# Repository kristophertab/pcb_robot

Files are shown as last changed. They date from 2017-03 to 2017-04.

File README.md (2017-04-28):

# PCB do robota
Płytka z mcu, optoizolowanym połączeniem uart, połączeniem st-link, kilkoma poziomami zasilania. Ma za zadanie sterować odczytywać dane z enkoderów i sterować, przez mostki, pracą silników
### Schemat
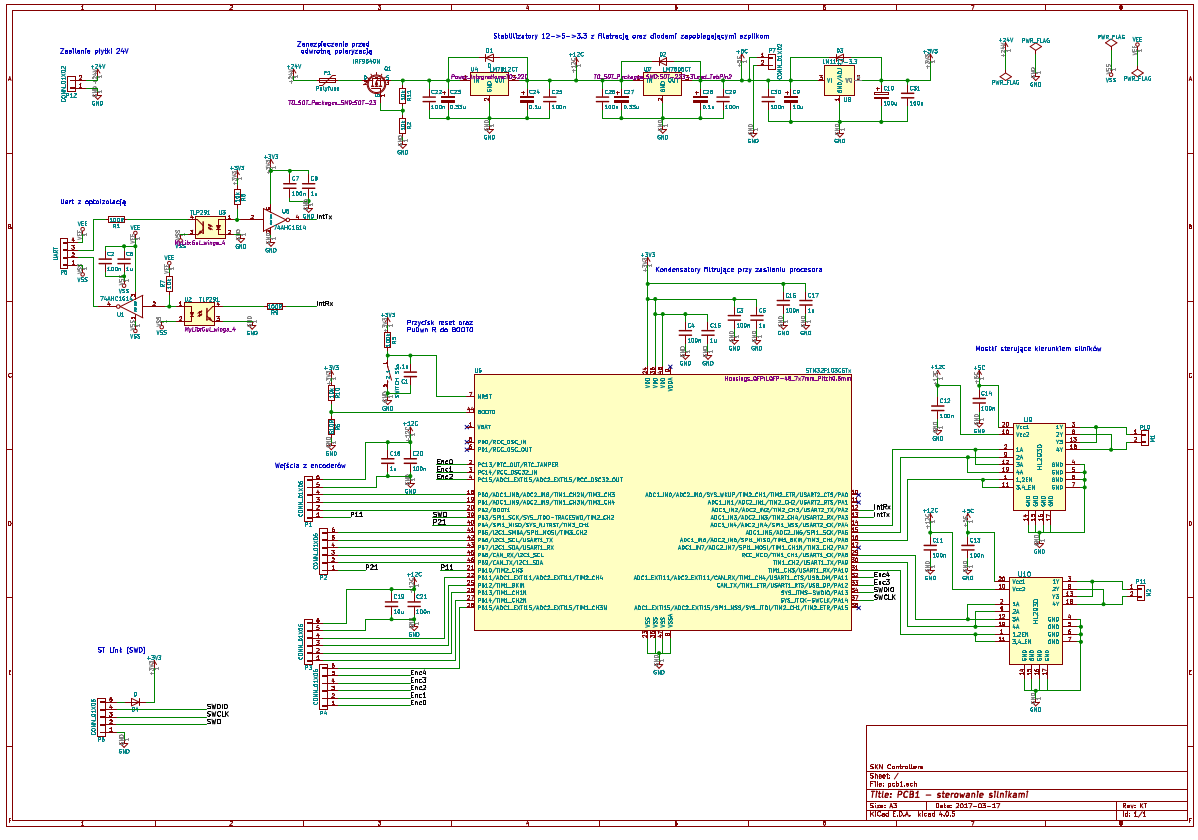
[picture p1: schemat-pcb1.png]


### PCB
Górna warstwa:

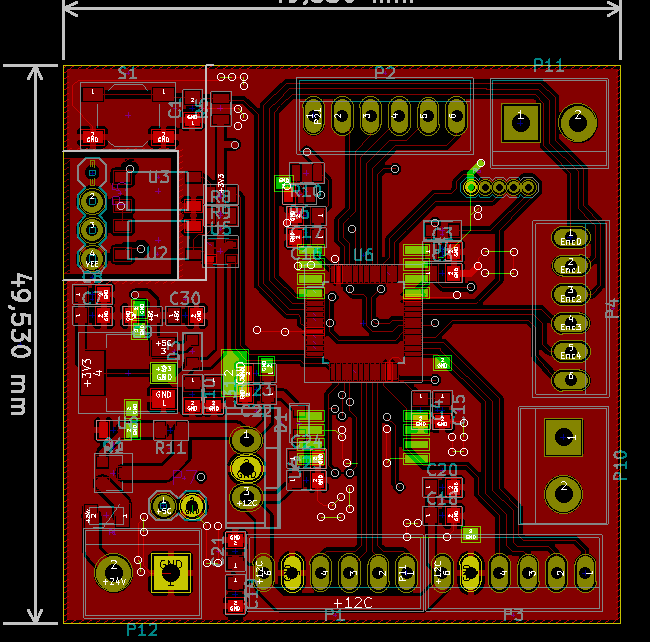
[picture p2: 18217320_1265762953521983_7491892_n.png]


Dolna warstwa:

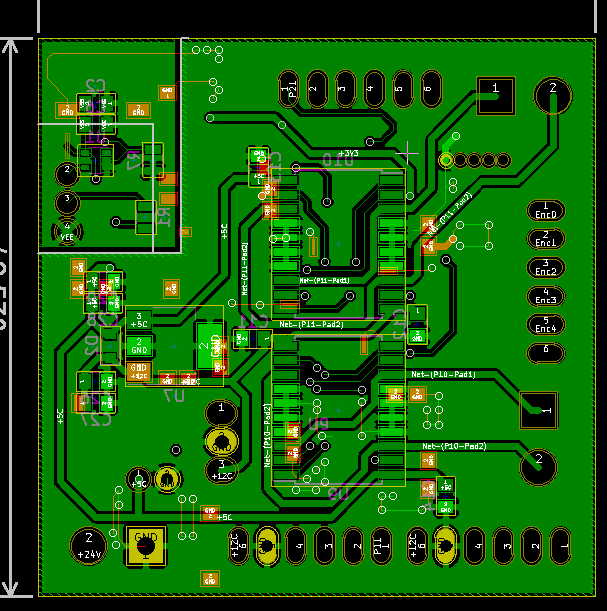
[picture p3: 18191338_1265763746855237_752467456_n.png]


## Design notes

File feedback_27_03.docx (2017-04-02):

1. Boot zworka

rys z manuala:

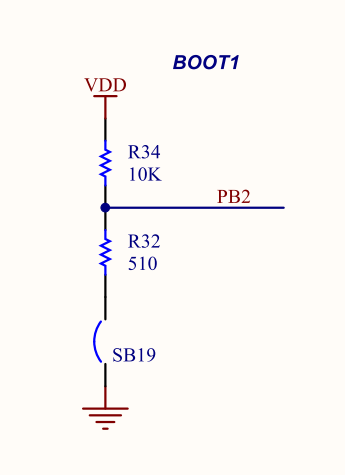
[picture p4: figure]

A tak na schemacie jest:

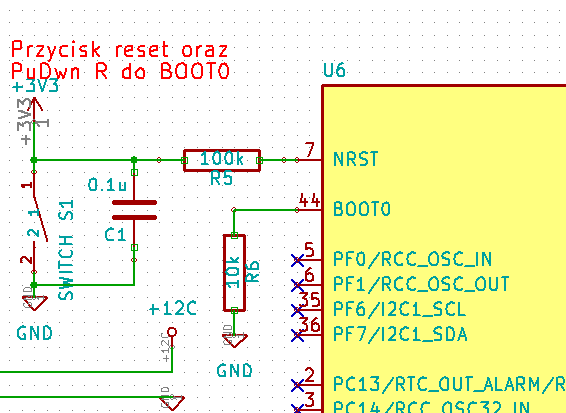
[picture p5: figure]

2. Dzielnik dla mosfeta wejściowego

tak na schemacie jest:

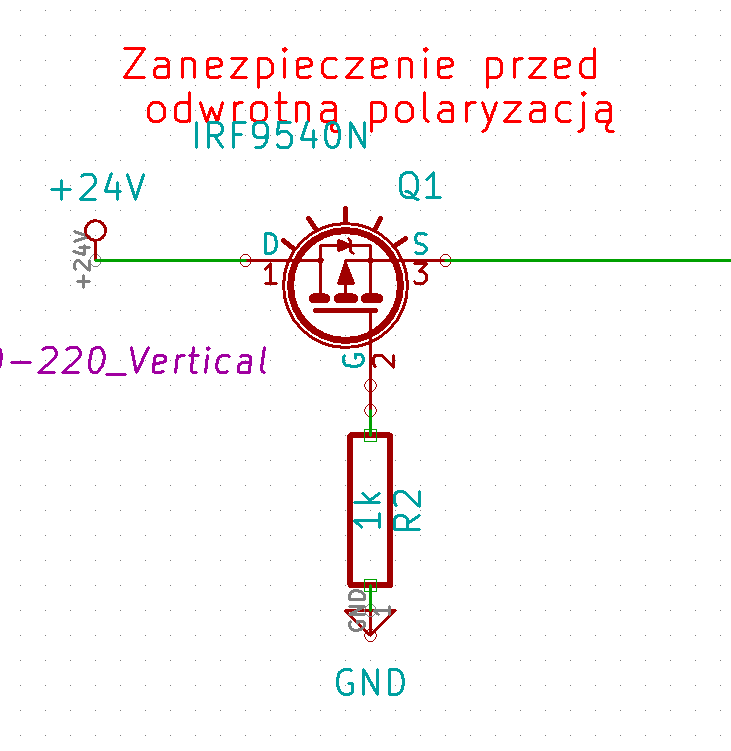
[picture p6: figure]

Powinno być tak:

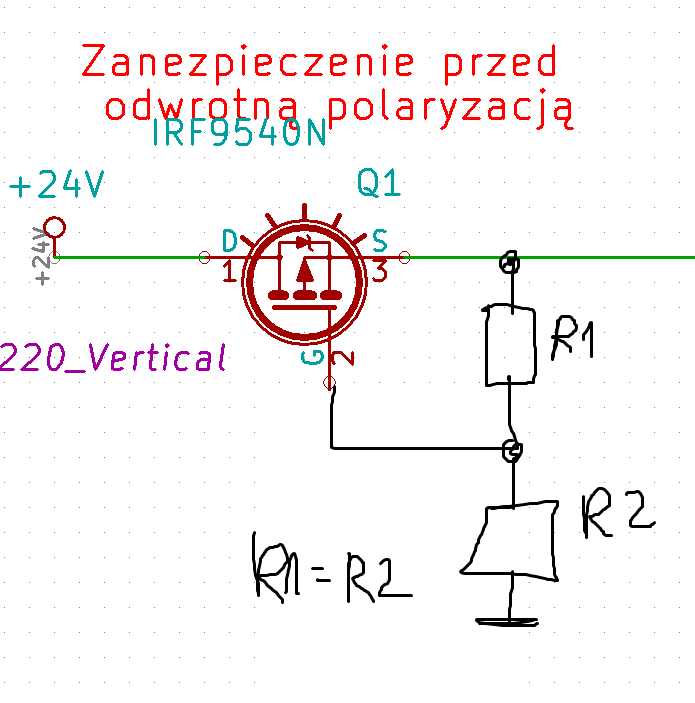
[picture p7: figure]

Ponieważ(nota katalogowa IRF5305 mosfet typu P):

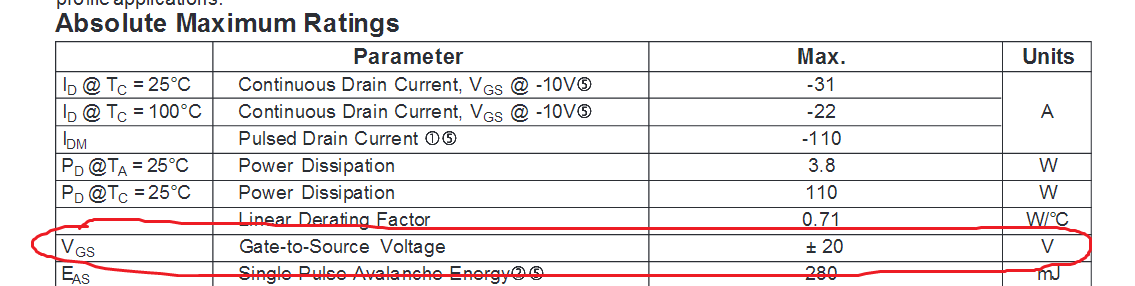
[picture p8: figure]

http://www.irf.com/product-info/datasheets/data/irf5305s.pdf

3. Rezystory poprawić(pull-up 10k i szeregowo rezystory 100R) i kondesatory dodac( 100nF i 1uF )

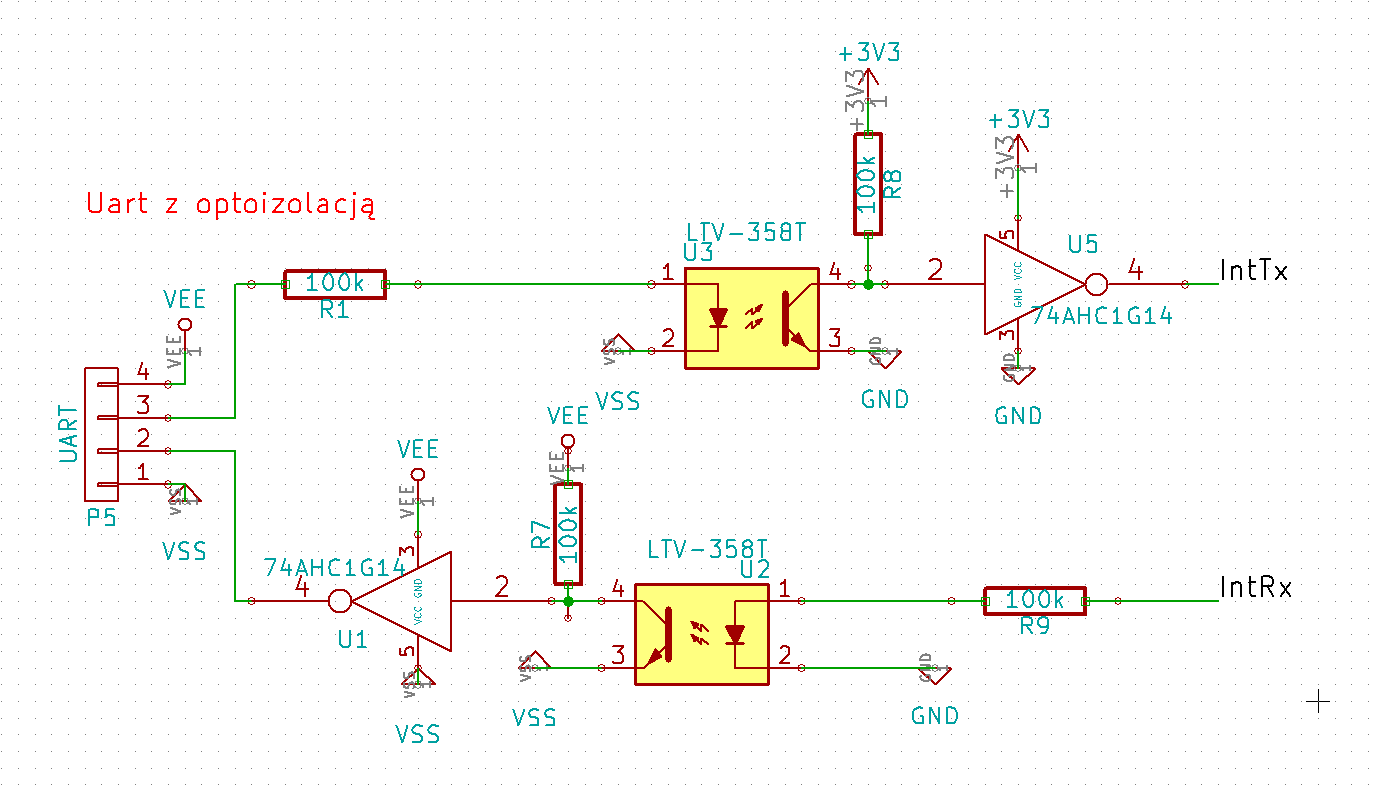
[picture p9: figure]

4. Bezpiecznik polimerowy na samym wejściu w napięciu 24V dac na 2A jakos
5. Ujednolisci symbol kondensatorow elektrolitycznych i dodac ceramiczne, po jednym na kazda strone stabilizatorów, wartości jakies 100nF

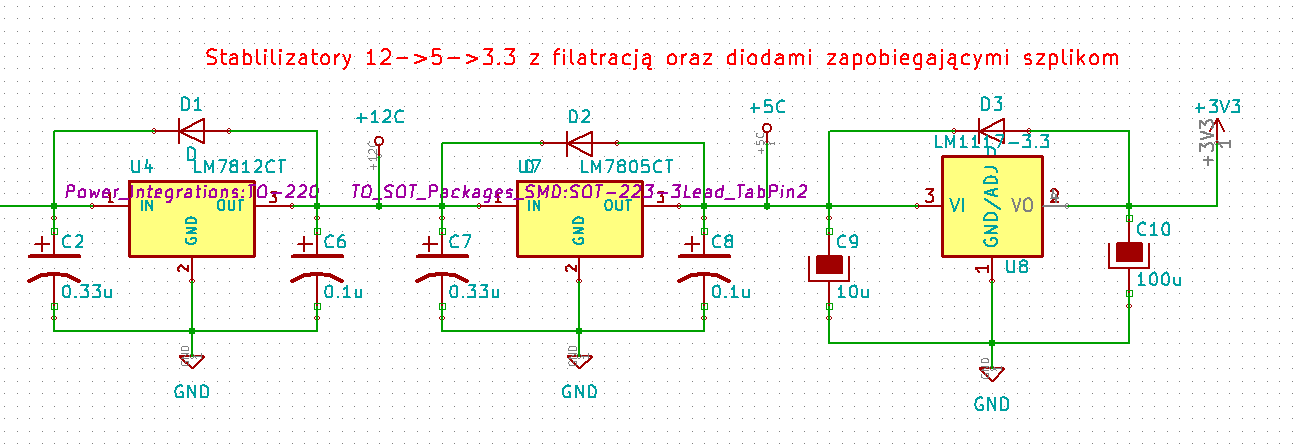
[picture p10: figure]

6. SWD zworke poprawić i odpowiednio podlaczyc

Manual:

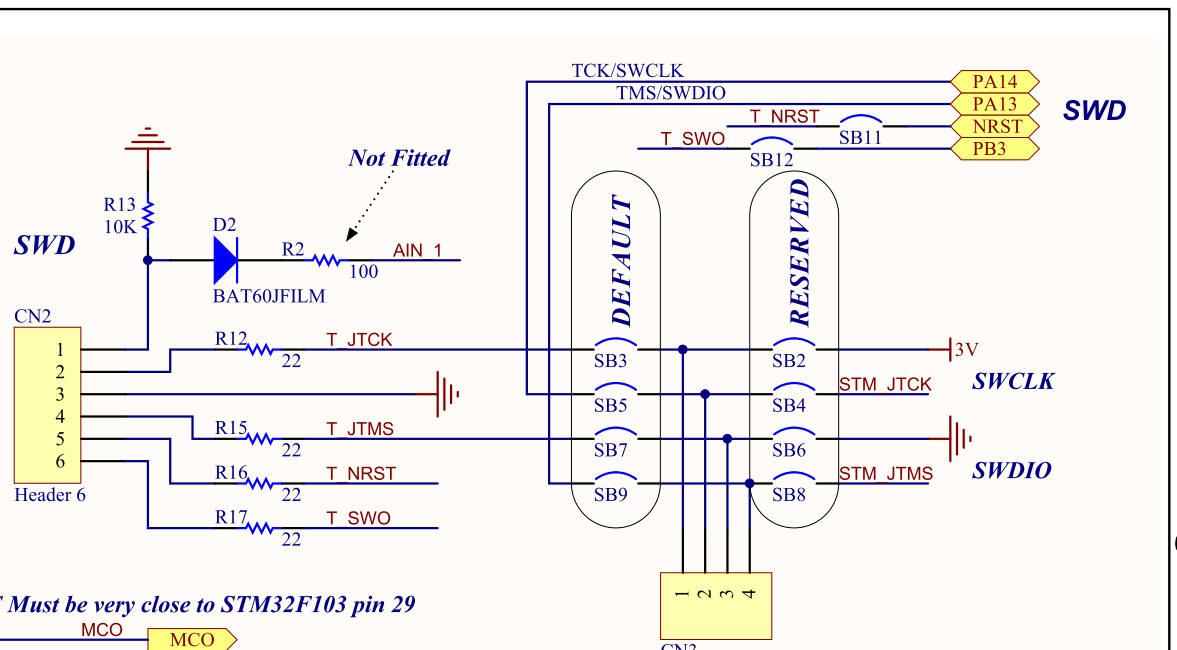
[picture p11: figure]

Tak jest na schemacie:

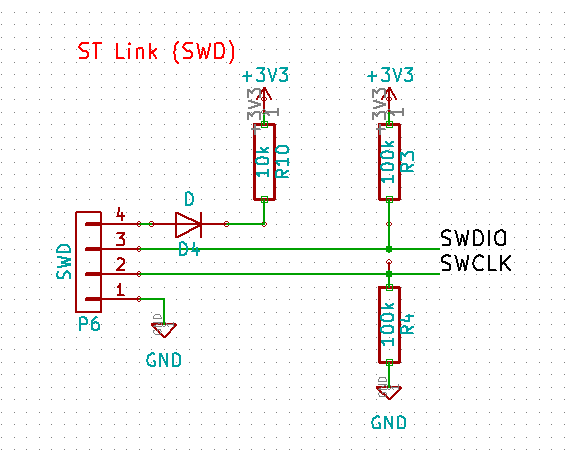
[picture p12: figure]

Dodatkowo: usunąć rezystor 100k miedzy dioda a 3.3V – inaczej nie zasilimy naszego układu

7. Zewrzec do masy Vss

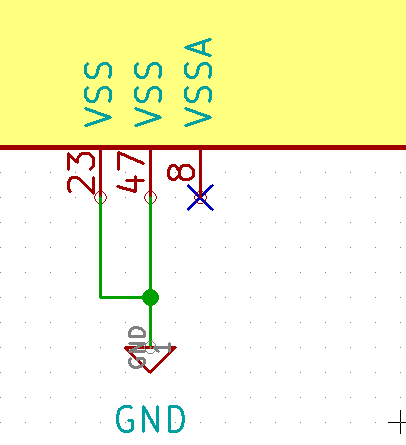
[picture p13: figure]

8. Dodac kondensatory 100nF i 1uF na wejścia zaislaniua do enkoderów

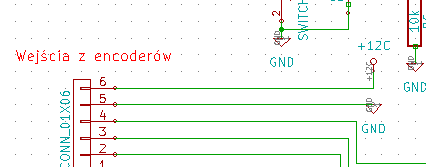
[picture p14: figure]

9. Reset podlaczenie poprawić

Manual:

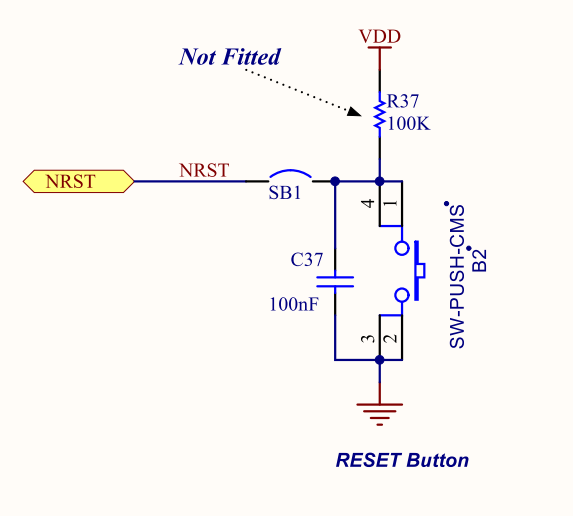
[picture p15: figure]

Schemat:

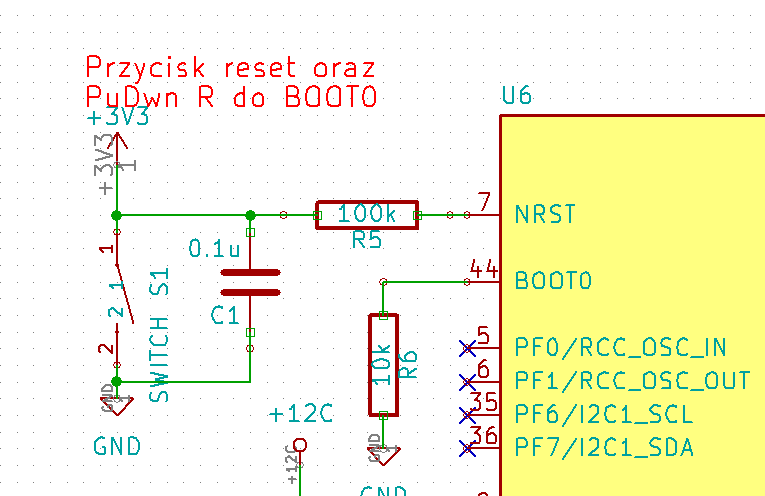
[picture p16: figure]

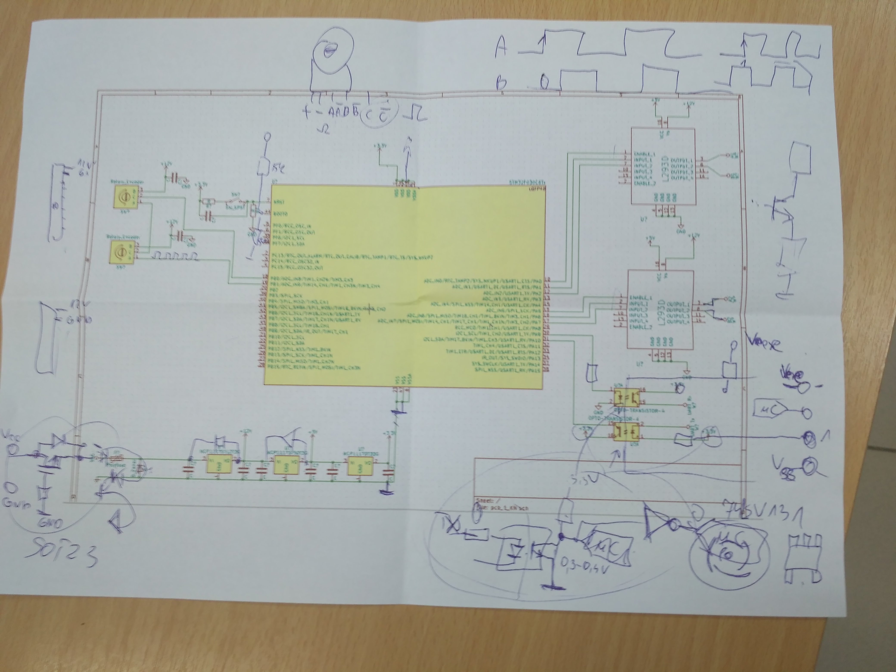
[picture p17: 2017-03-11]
poprawki_pcb1.jpg

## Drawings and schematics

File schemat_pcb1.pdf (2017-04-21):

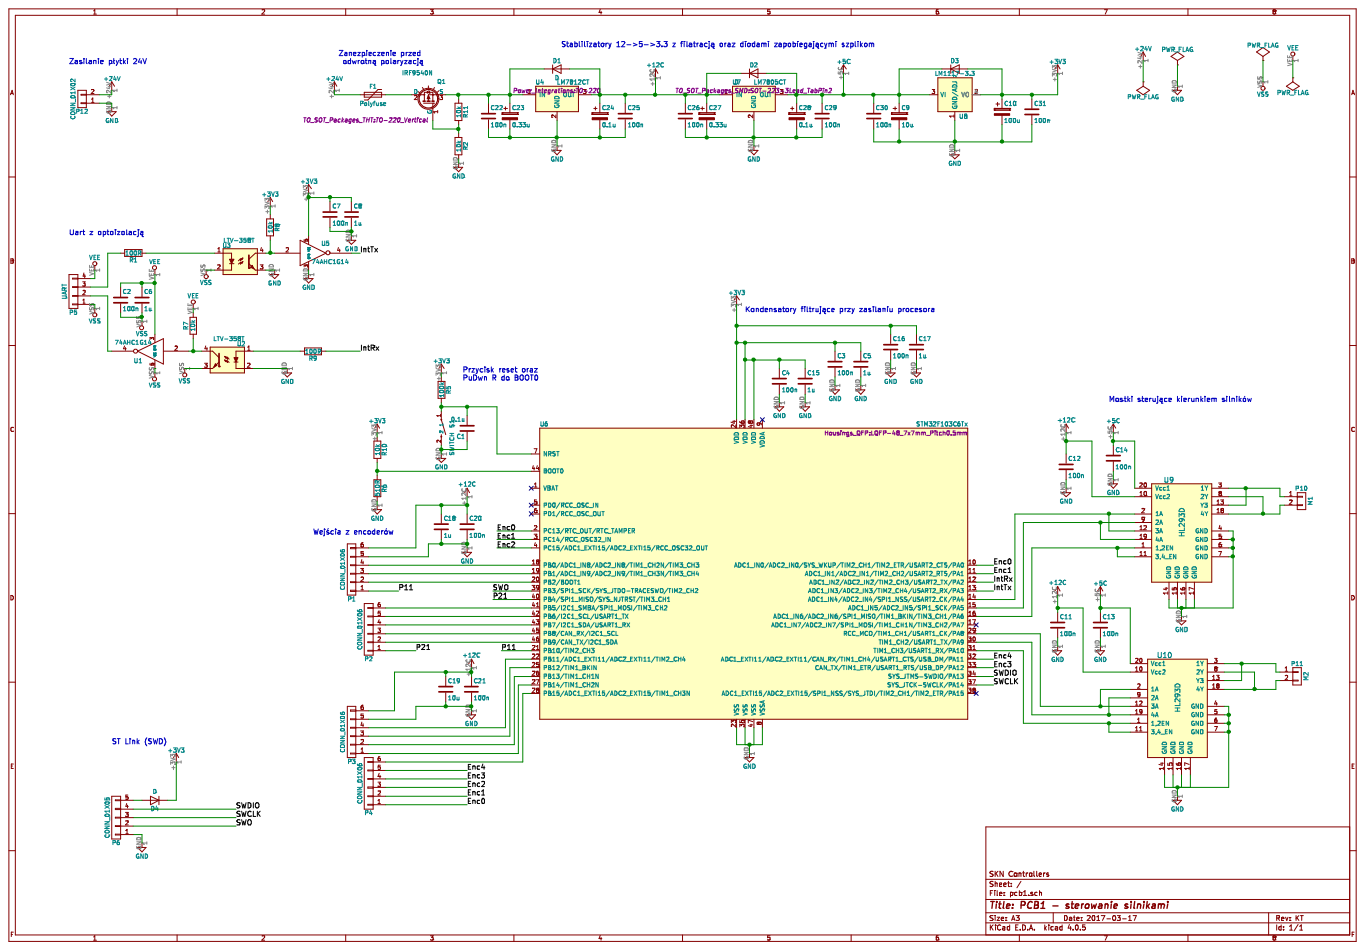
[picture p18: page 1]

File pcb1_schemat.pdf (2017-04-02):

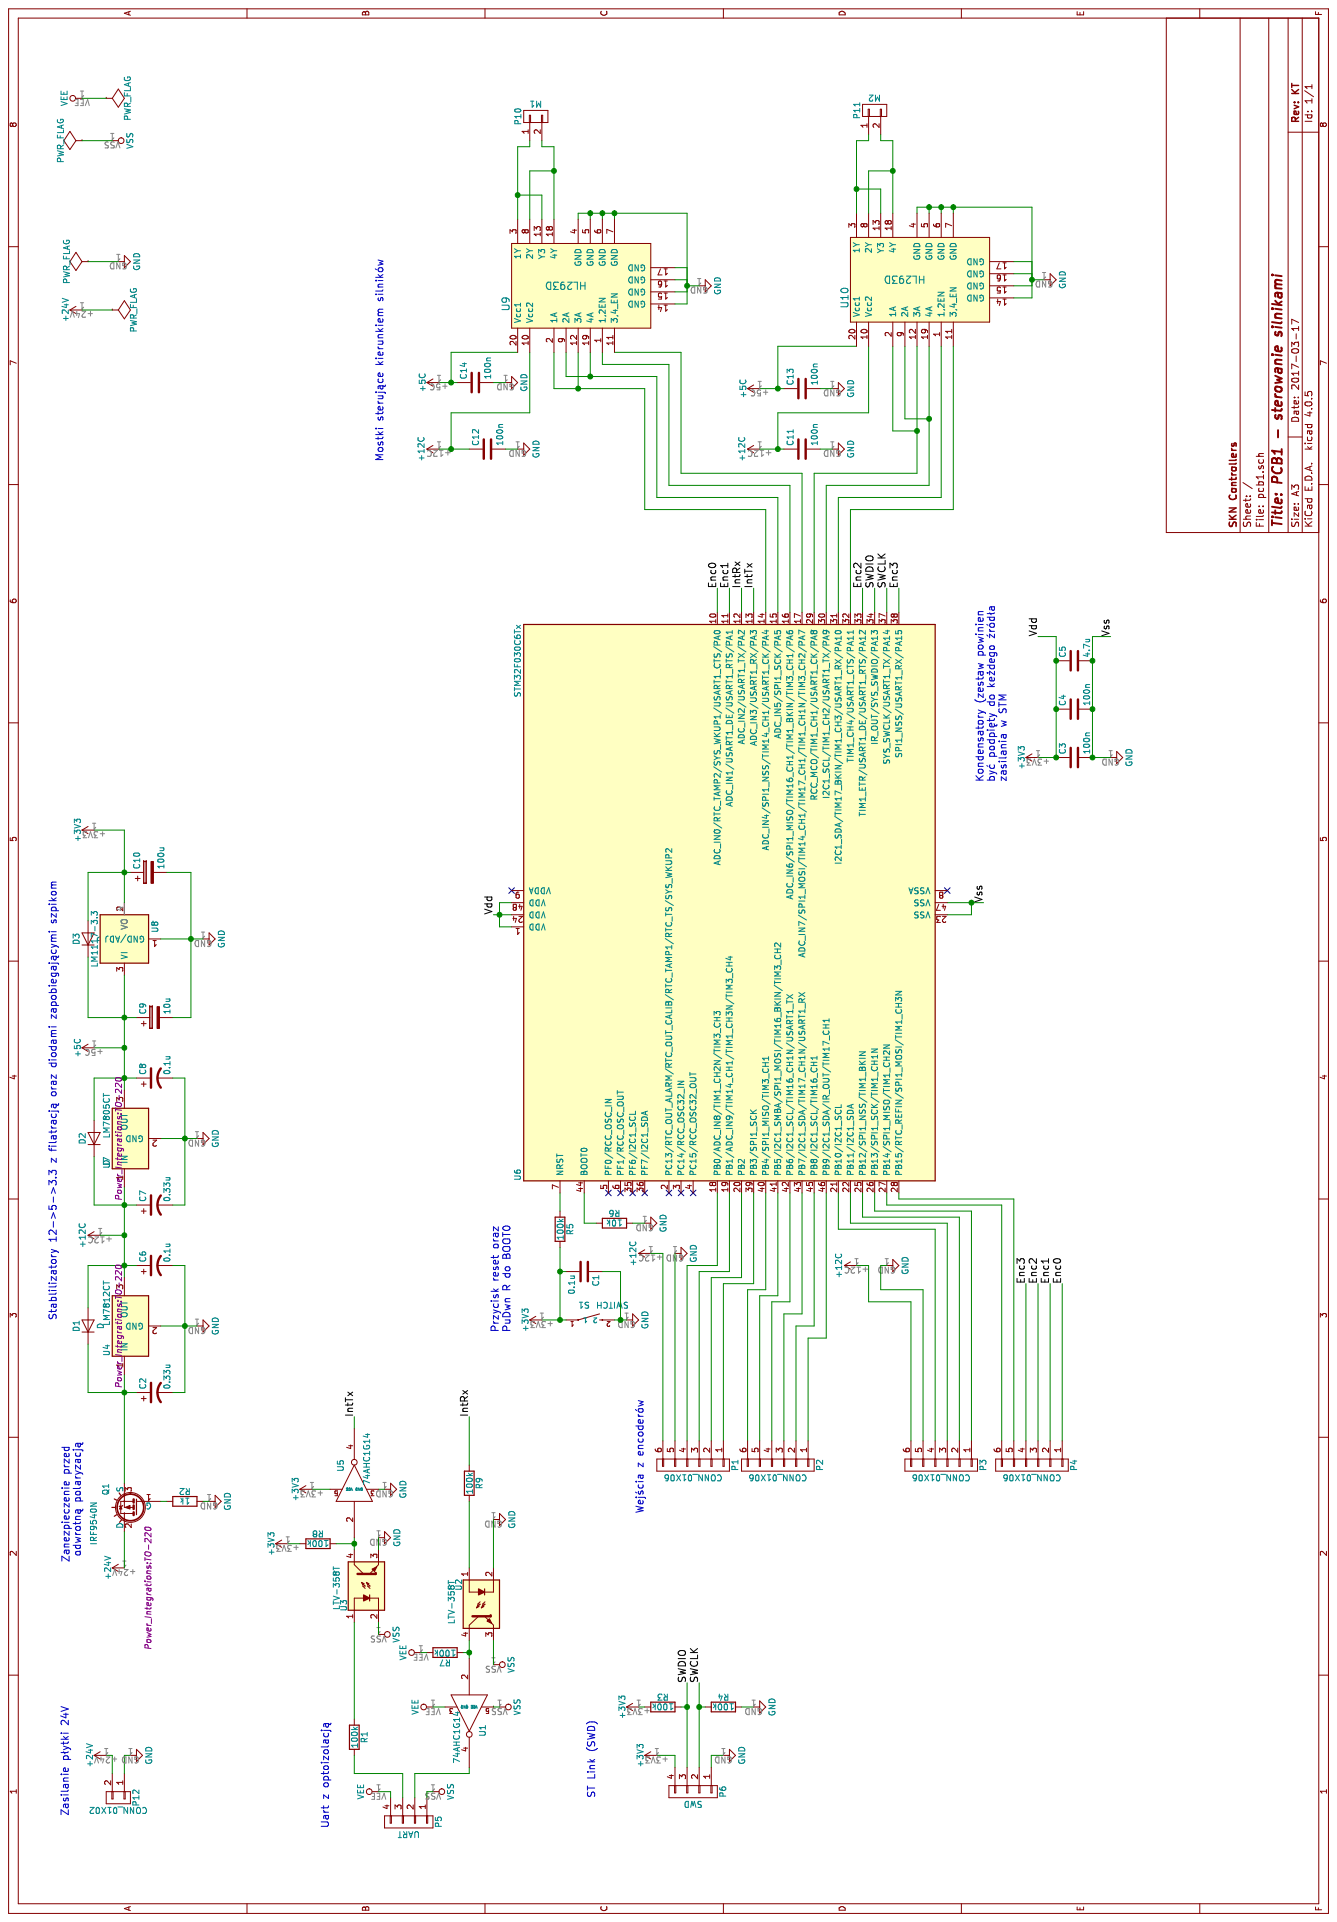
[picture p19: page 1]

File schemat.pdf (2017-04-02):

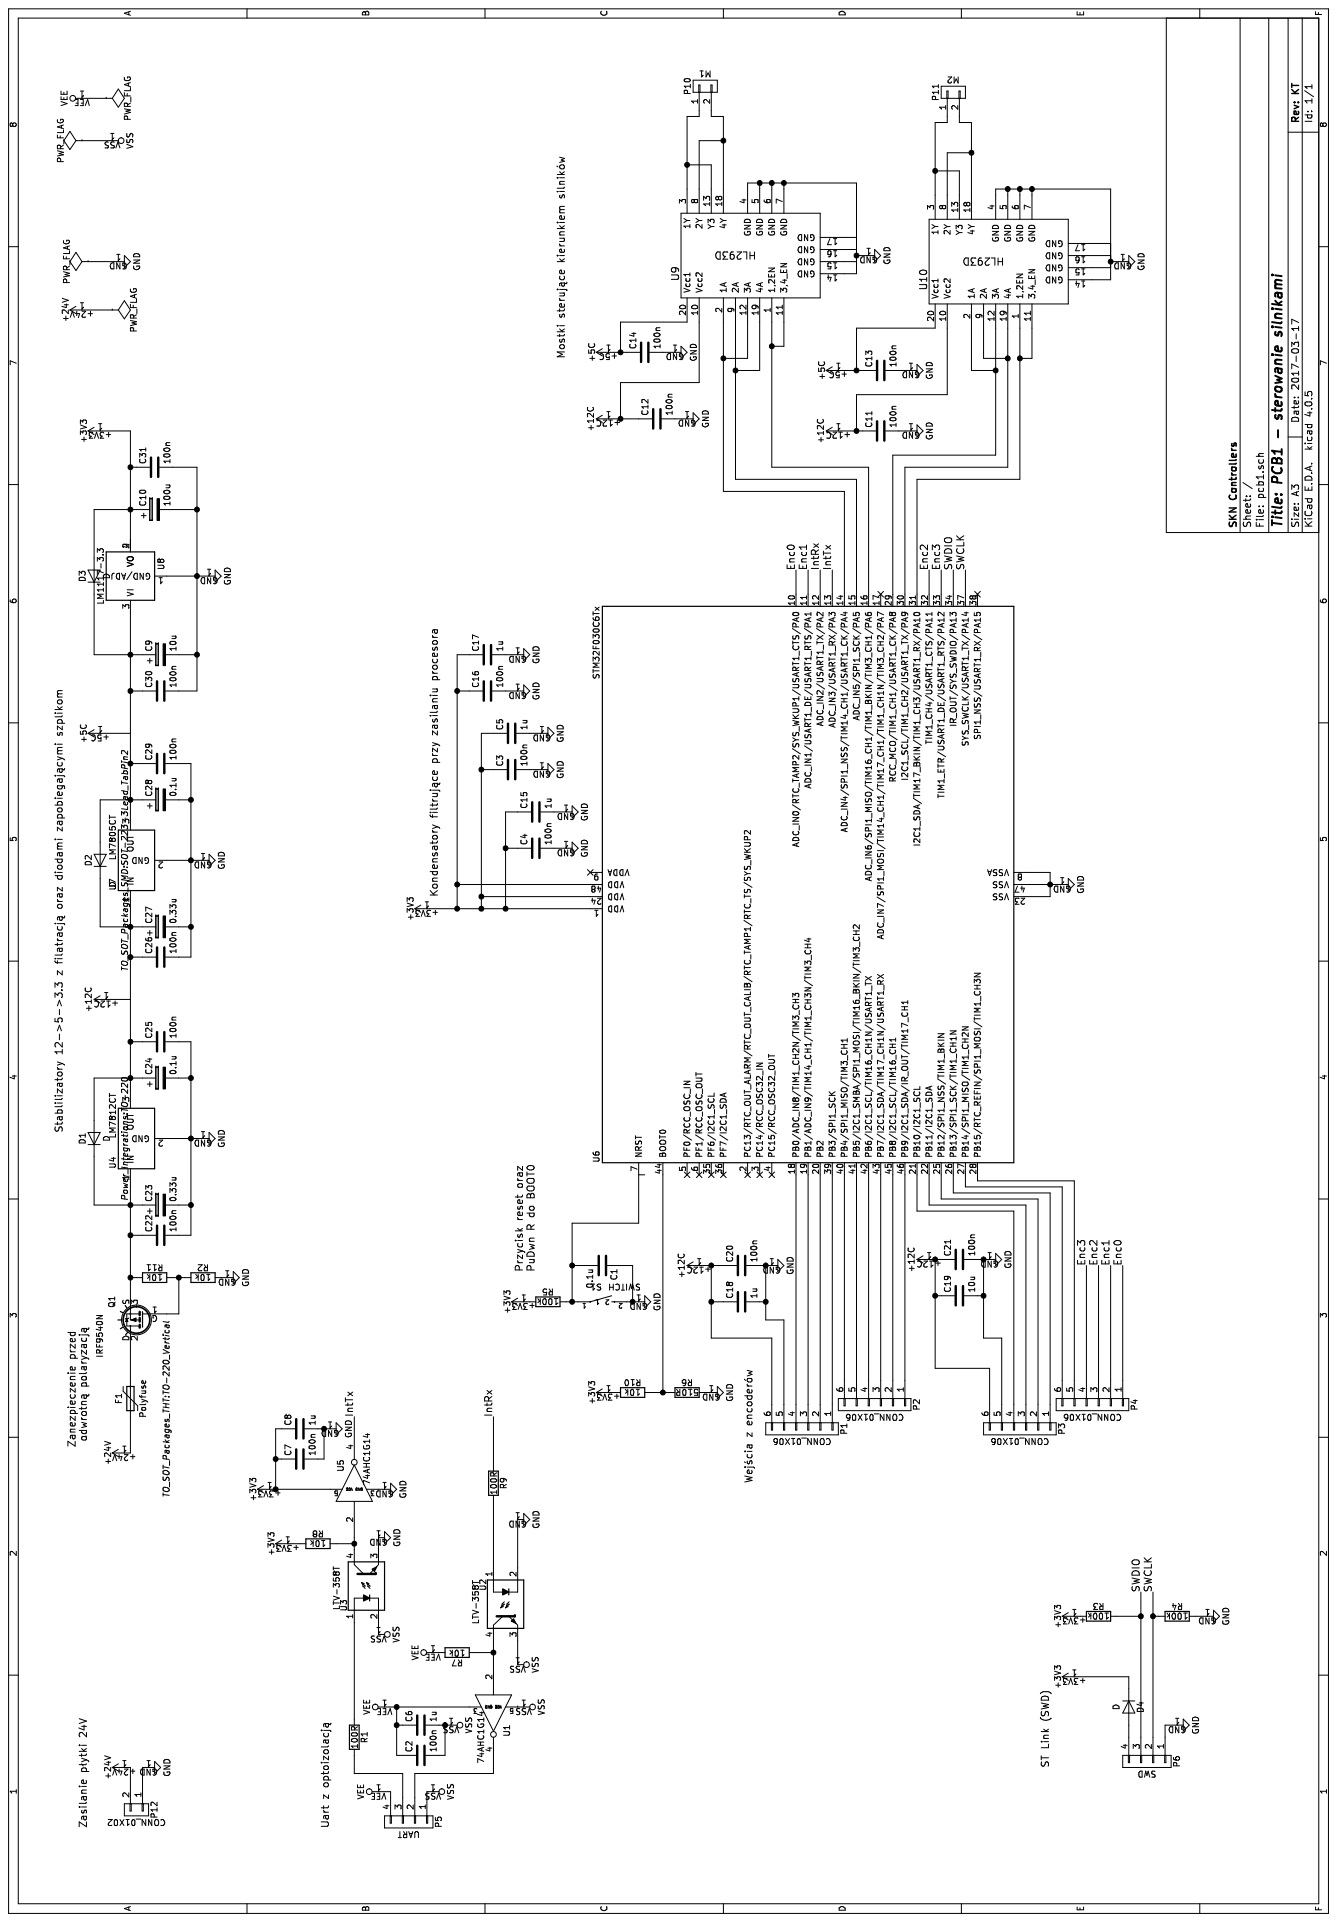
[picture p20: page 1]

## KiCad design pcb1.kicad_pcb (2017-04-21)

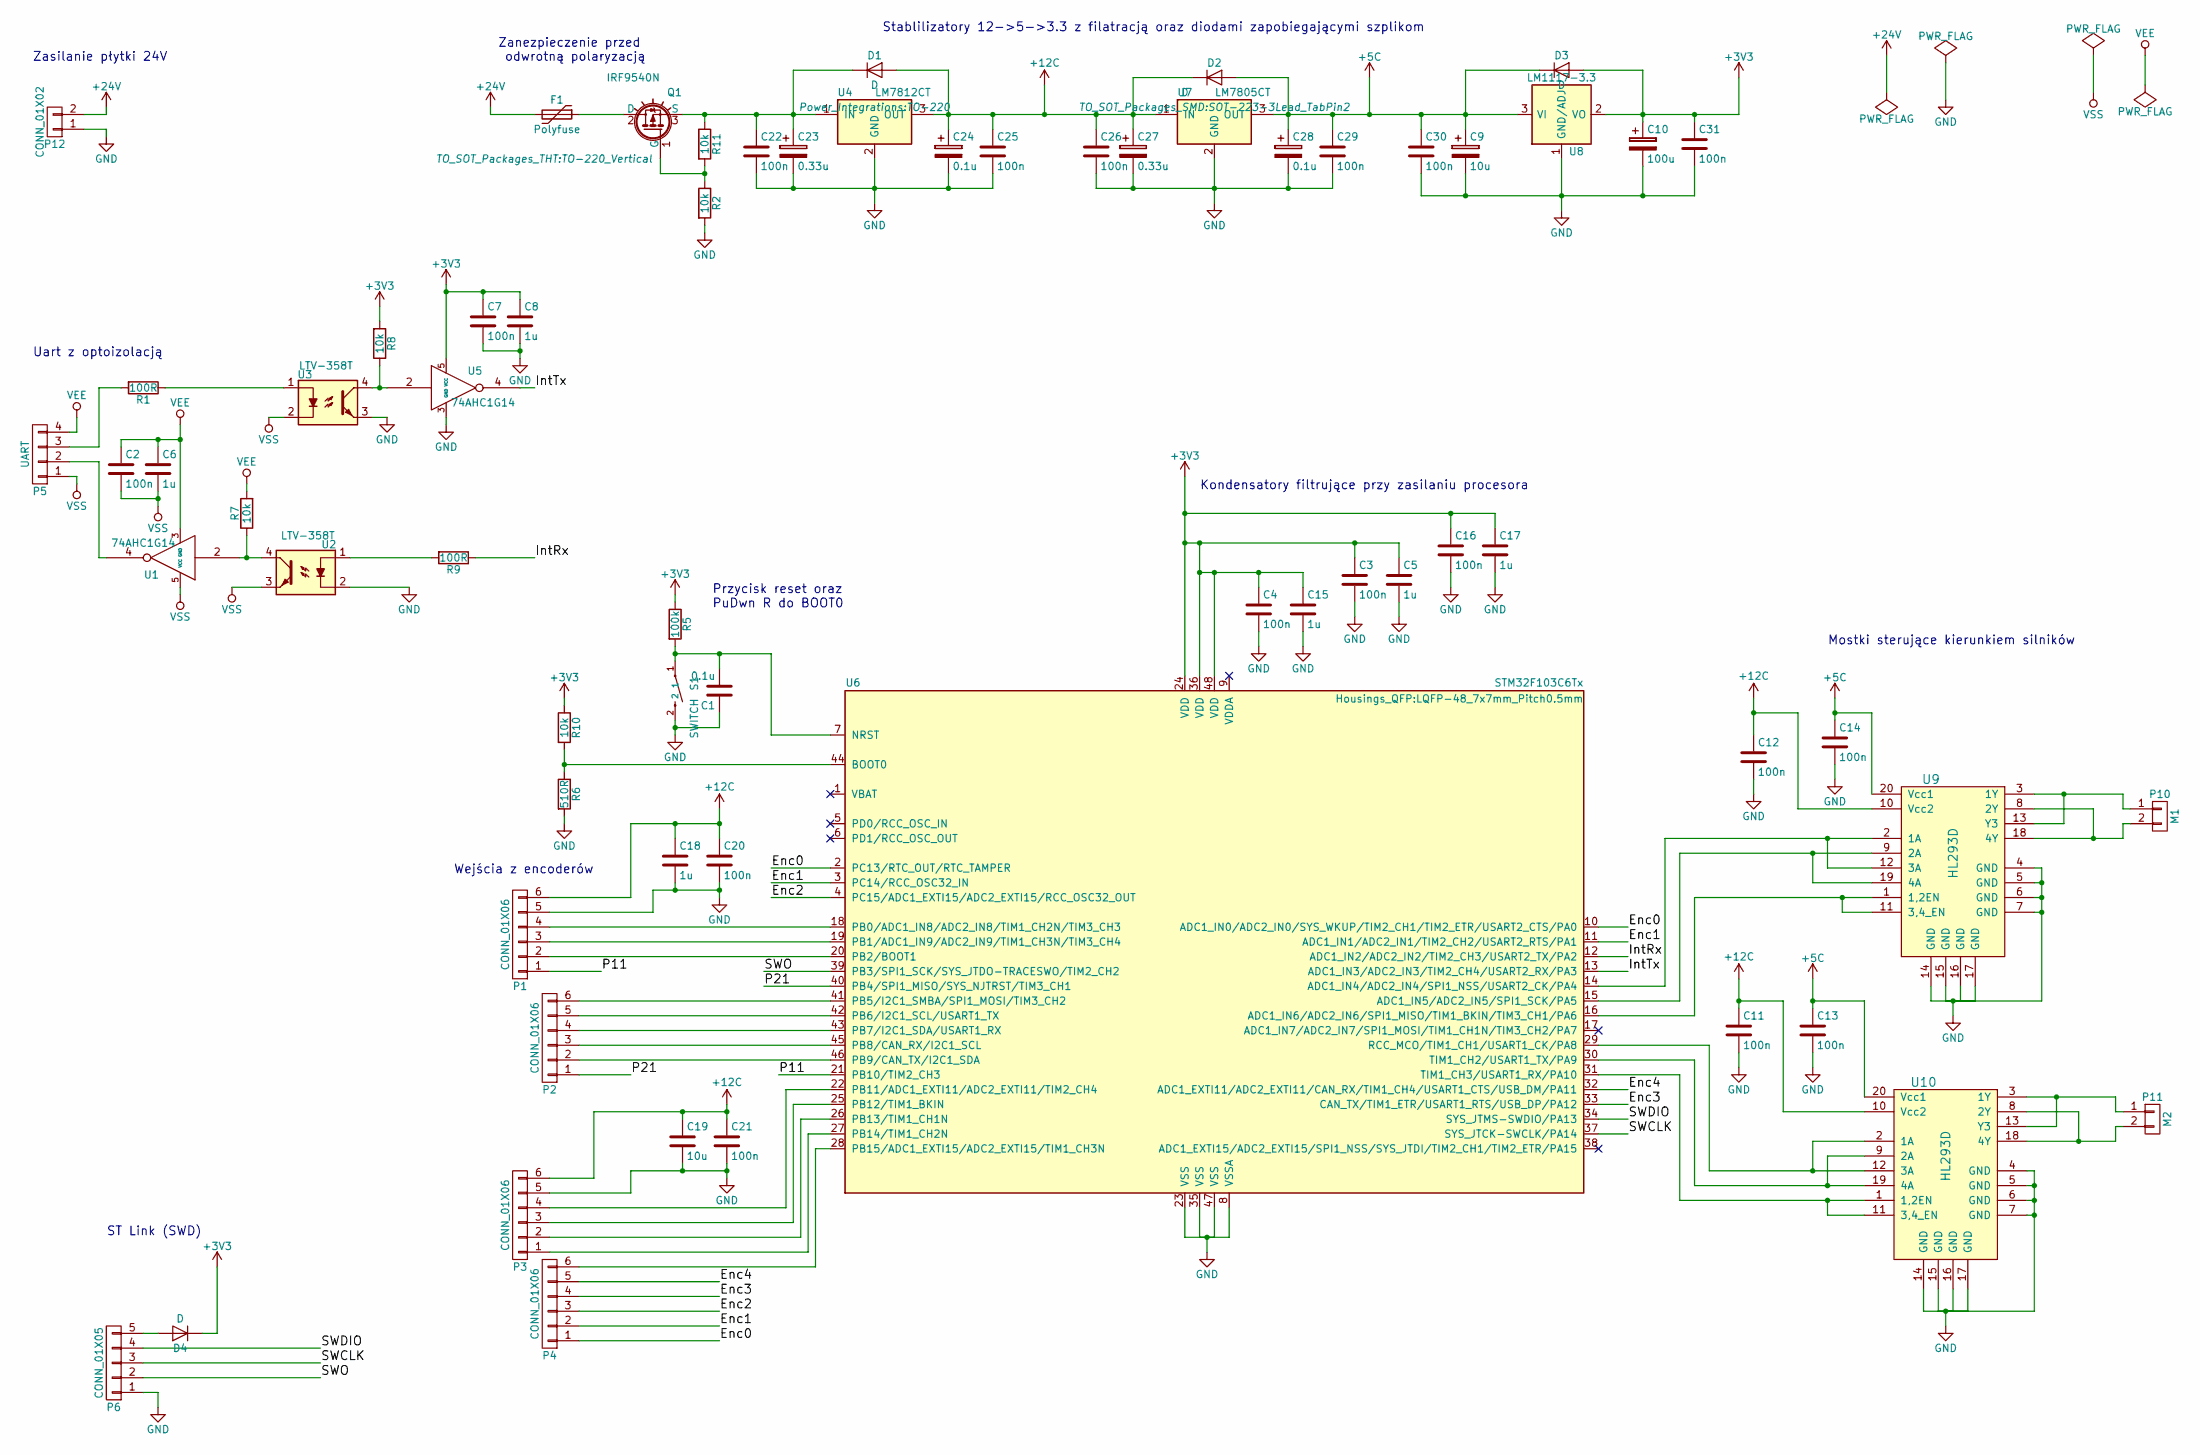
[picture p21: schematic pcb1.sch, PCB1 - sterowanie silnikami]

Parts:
C1, C24, C28: 0.1u; C_0805
C2, C3, C4, C7, C11, C12, C13, C14, C16, C20, C21, C22, C25, C26, C29, C30, C31: 100n; C_0805
C5, C6, C8, C15, C17, C18: 1u; C_0805
C9, C19: 10u; C_0805
C10: 100u; C_0805
C23, C27: 0.33u; C_0805
D1, D2, D3, D4: D; D_0805
F1: Polyfuse; SparkFun-PTC-1206
P1, P2, P3, P4: CONN_01X06; PINHEAD1-6
P5: UART; SparkFun-1X04
P6: CONN_01X05; SparkFun-1X05-1.27MM
P10: M1; bornier2
P11: M2; bornier2
P12: CONN_01X02; bornier2
Q1: IRF9540N; TO-220_Vertical
R1, R9: 100R; R_0805
R2, R7, R8, R10, R11: 10k; R_0805
R5: 100k; R_0805
R6: 510R; R_0805
S1: SWITCH; SW_SPST_TL3342
U1, U5: 74AHC1G14; SOT-353_SC-70-5
U2, U3: LTV-358T; SW_DIP_x2_W6.15mm_Slide_Omron_A6H
U4: LM7812CT; TO-220
U6: STM32F103C6Tx; LQFP-48_7x7mm_Pitch0.5mm
U7: LM7805CT; SOT-223-3Lead_TabPin2
U8: LM1117-3.3; SOT-223
U9, U10: HL293D; SOIC-20W_7.5x12.8mm_Pitch1.27mm

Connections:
+3V3: C3.1, C4.1, C5.1, C7.1, C8.1, C10.1, C15.1, C16.1, C17.1, C31.1, D3.2 (A), D4.1 (K), R5.1, R8.2, R10.1, U5.5 (VCC), U6.24 (VDD), U6.36 (VDD), U6.48 (VDD), U8.2 (VO), U8.4 (VO)
+5C: C9.1, C13.1, C14.1, C28.1, C29.1, C30.1, D2.2 (A), D3.1 (K), U7.3 (OUT), U8.3 (VI), U9.20 (Vcc1), U10.20 (Vcc1)
+12C: C11.1, C12.1, C18.1, C19.1, C20.1, C21.1, C24.1, C25.1, C26.1, C27.1, D1.2 (A), D2.1 (K), P1.6, P3.6, U4.3 (OUT), U7.1 (IN), U9.10 (Vcc2), U10.10 (Vcc2)
+24V: F1.2, P12.2
/Enc0: P4.1, U6.2 (PC13/RTC_OUT/RTC_TAMPER), U6.10 (ADC1_IN0/ADC2_IN0/SYS_WKUP/TIM2_CH1/TIM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)
/Enc1: P4.2, U6.3 (PC14/RCC_OSC32_IN), U6.11 (ADC1_IN1/ADC2_IN1/TIM2_CH2/USART2_RTS/P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)
/Enc2: P4.3, U6.4 (PC15/ADC1_EXTI15/ADC2_EXTI15/RCC_OSC32_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)
/Enc3: P4.4, U6.33 (CAN_TX/TIM1_ETR/USART1_RTS/USB_DP/PA12)
/Enc4: P4.5, U6.32 (ADC1_EXTI11/ADC2_EXTI11/CAN_RX/TIM1_CH4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)
/IntRx: R9.1, U6.12 (ADC1_IN2/ADC2_IN2/TIM2_CH3/USART2_TX/PA2)
/IntTx: U5.4, U6.13 (ADC1_IN3/ADC2_IN3/TIM2_CH4/USART2_RX/PA3)
/P11: P1.1, U6.21 (PB10/TIM2_CH3)
/P21: P2.1, U6.40 (PB4/SPI1_MISO/SYS_NJTRST/TIM3_CH1)
/SWCLK: P6.3, U6.37 (SYS_JTCK-SWCLK/PA14)
/SWDIO: P6.4, U6.34 (SYS_JTMS-SWDIO/PA13)
/SWO: P6.2, U6.39 (PB3/SPI1_SCK/SYS_JTDO-TRACESWO/TIM2_CH2)
GND: C1.1, C3.2, C4.2, C5.2, C7.2, C8.2, C9.2, C10.2, C11.2, C12.2, C13.2, C14.2, C15.2, C16.2, C17.2, C18.2, C19.2, C20.2, C21.2, C22.2, C23.2, C24.2, C25.2, C26.2, C27.2, C28.2, C29.2, C30.2, C31.2, P1.5, P3.5, P6.1, P12.1, R2.2, R6.2, S1.2, U2.2, U3.3, U4.2 (GND), U5.3 (GND), U6.8 (VSSA), U6.23 (VSS), U6.35 (VSS), U6.47 (VSS), U7.2 (GND), U8.1 (GND/ADJ), U9.4 (GND), U9.5 (GND), U9.6 (GND), U9.7 (GND), U9.14 (GND), U9.15 (GND), U9.16 (GND), U9.17 (GND), U10.4 (GND), U10.5 (GND), U10.6 (GND), U10.7 (GND), U10.14 (GND), U10.15 (GND), U10.16 (GND), U10.17 (GND)
unnamed: C1.2, R5.2, S1.1, U6.7 (NRST)
unnamed: C22.1, C23.1, D1.1 (K), Q1.3 (S), R11.1, U4.1 (IN)
unnamed: D4.2 (A), P6.5
unnamed: F1.1, Q1.2 (D)
unnamed: P1.2, U6.20 (PB2/BOOT1)
unnamed: P1.3, U6.19 (PB1/ADC1_IN9/ADC2_IN9/TIM1_CH3N/TIM3_CH4)
unnamed: P1.4, U6.18 (PB0/ADC1_IN8/ADC2_IN8/TIM1_CH2N/TIM3_CH3)
unnamed: P2.2, U6.46 (PB9/CAN_TX/I2C1_SDA)
unnamed: P2.3, U6.45 (PB8/CAN_RX/I2C1_SCL)
unnamed: P2.4, U6.43 (PB7/I2C1_SDA/USART1_RX)
unnamed: P2.5, U6.42 (PB6/I2C1_SCL/USART1_TX)
unnamed: P2.6, U6.41 (PB5/I2C1_SMBA/SPI1_MOSI/TIM3_CH2)
unnamed: P3.1, U6.27 (PB14/TIM1_CH2N)
unnamed: P3.2, U6.26 (PB13/TIM1_CH1N)
unnamed: P3.3, U6.25 (PB12/TIM1_BKIN)
unnamed: P3.4, U6.22 (PB11/ADC1_EXTI11/ADC2_EXTI11/TIM2_CH4)
unnamed: P4.6, U6.28 (PB15/ADC1_EXTI15/ADC2_EXTI15/TIM1_CH3N)
unnamed: P5.2, U1.4
unnamed: P5.3, R1.2
unnamed: P10.1, U9.3 (1Y), U9.13 (Y3)
unnamed: P10.2, U9.8 (2Y), U9.18 (4Y)
unnamed: P11.1, U10.3 (1Y), U10.13 (Y3)
unnamed: P11.2, U10.8 (2Y), U10.18 (4Y)
unnamed: Q1.1 (G), R2.1, R11.2
unnamed: R1.1, U3.1
unnamed: R7.1, U1.2, U2.4
unnamed: R8.1, U3.4, U5.2
unnamed: R9.2, U2.1
unnamed: R6.1, R10.2, U6.44 (BOOT0)
unnamed: U6.14 (ADC1_IN4/ADC2_IN4/SPI1_NSS/USART2_CK/PA4), U9.2 (1A), U9.12 (3A)
unnamed: U6.15 (ADC1_IN5/ADC2_IN5/SPI1_SCK/PA5), U9.9 (2A), U9.19 (4A)
unnamed: U6.16 (ADC1_IN6/ADC2_IN6/SPI1_MISO/TIM1_BKIN/T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), U9.1 (1,2EN), U9.11 (3,4_EN)
unnamed: U6.31 (TIM1_CH3/USART1_RX/PA10), U10.1 (1,2EN), U10.11 (3,4_EN)
unnamed: U6.29 (RCC_MCO/TIM1_CH1/USART1_CK/PA8), U10.2 (1A), U10.12 (3A)
unnamed: U6.30 (TIM1_CH2/USART1_TX/PA9), U10.9 (2A), U10.19 (4A)
VEE: C2.1, C6.1, P5.4, R7.2, U1.3 (GND)
VSS: C2.2, C6.2, P5.1, U1.5 (VCC), U2.3, U3.2

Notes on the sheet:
Stablilizatory 12->5->3.3 z filatracją oraz diodami zapobiegającymi szplikom
Zanezpieczenie przed odwrotną polaryzacją
Mostki sterujące kierunkiem silników
Uart z optoizolacją
ST Link (SWD)
Zasilanie płytki 24V
Kondensatory filtrujące przy zasilaniu procesora
Wejścia z encoderów
Przycisk reset oraz PuDwn R do BOOT0

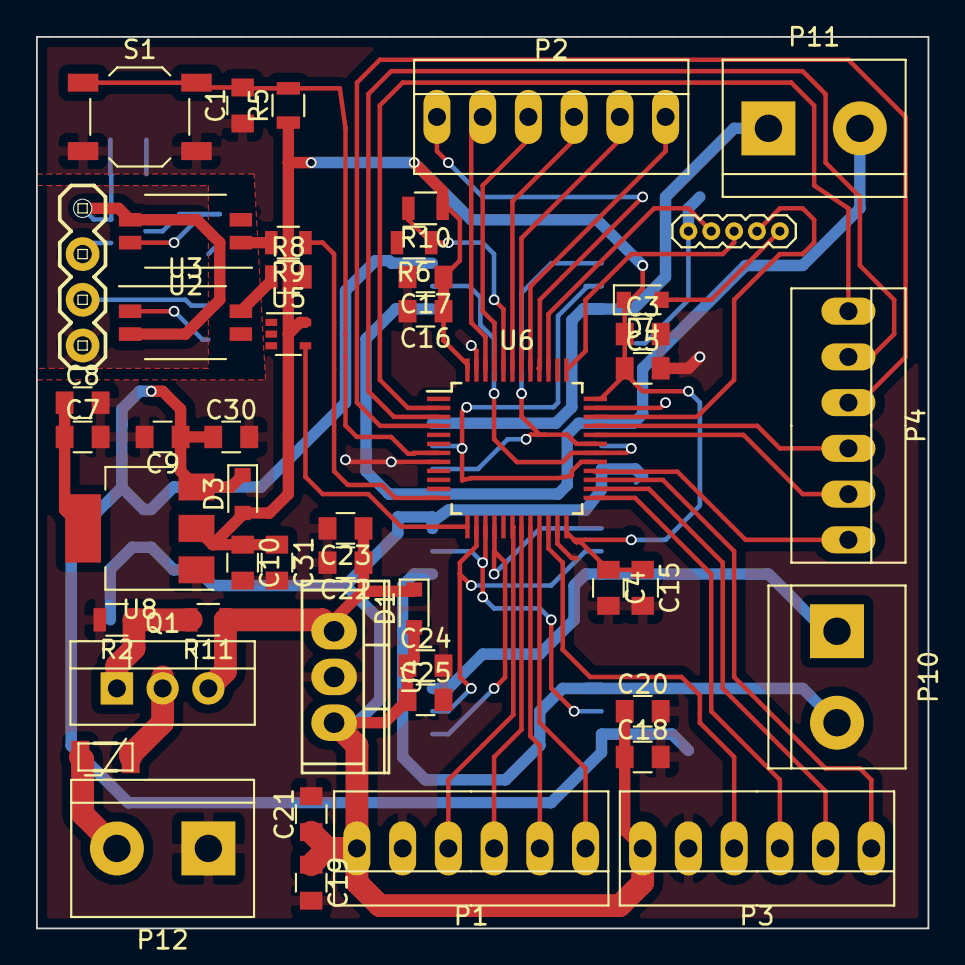
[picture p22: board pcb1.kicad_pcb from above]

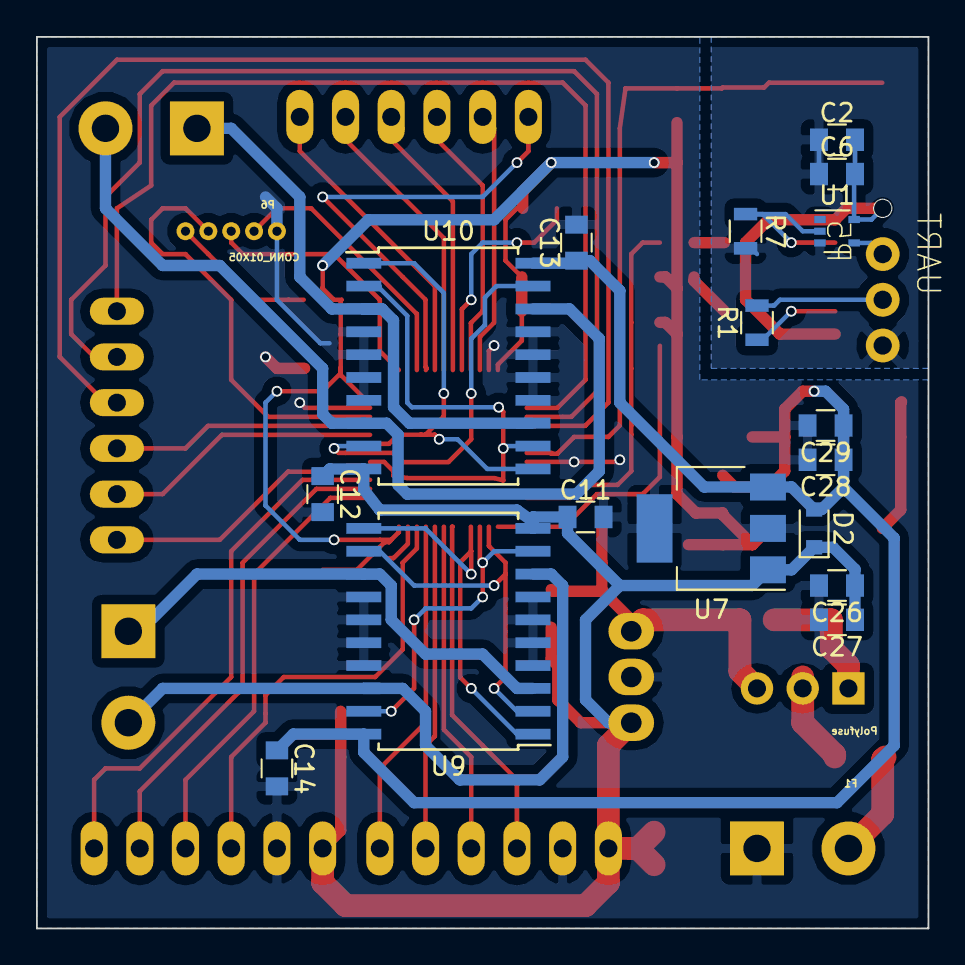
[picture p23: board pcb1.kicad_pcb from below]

Board: 2 copper layers, 49.5 x 49.5 mm, 66 parts (17 on the bottom side), 54 nets.

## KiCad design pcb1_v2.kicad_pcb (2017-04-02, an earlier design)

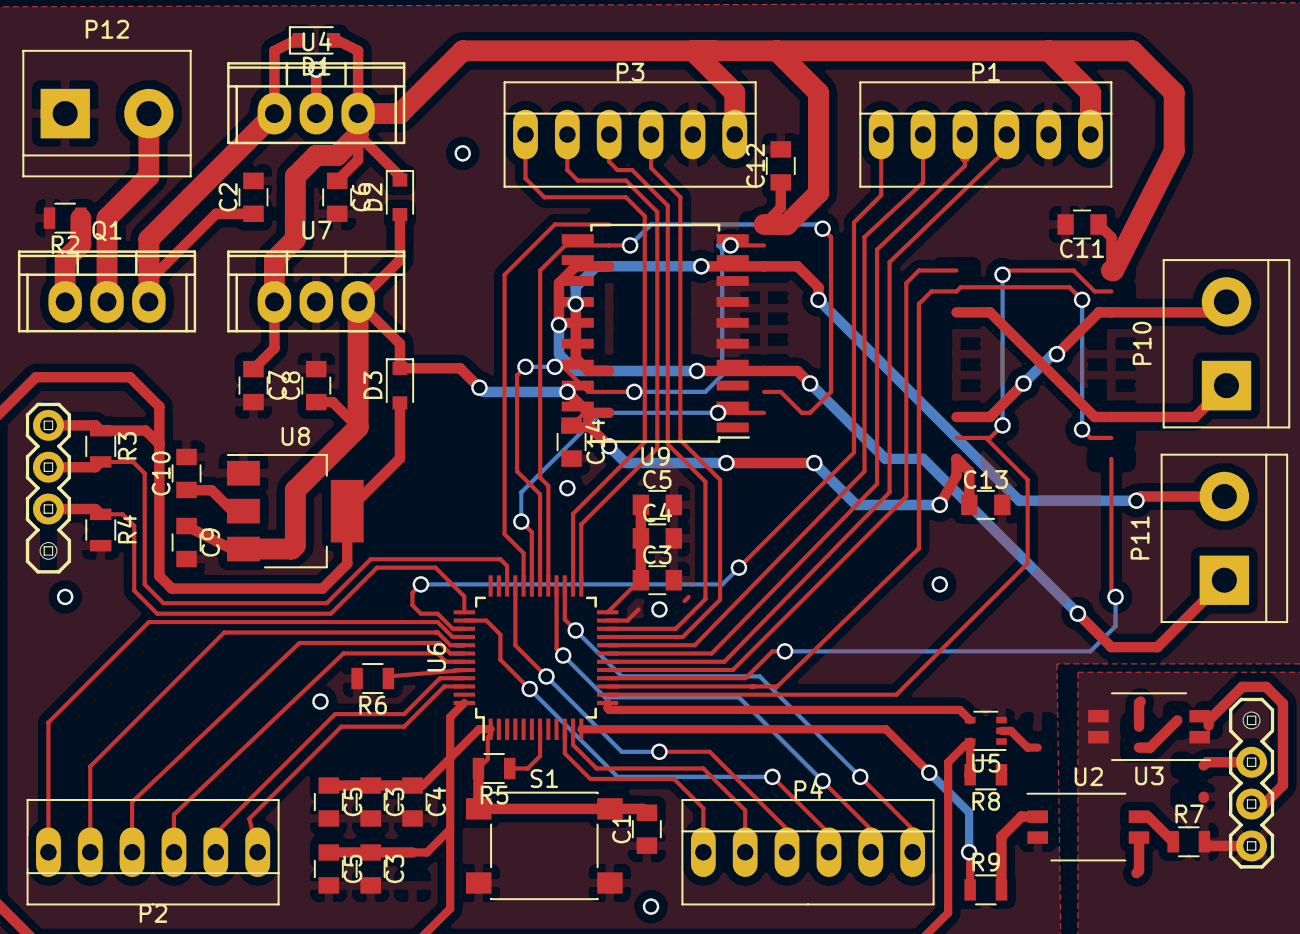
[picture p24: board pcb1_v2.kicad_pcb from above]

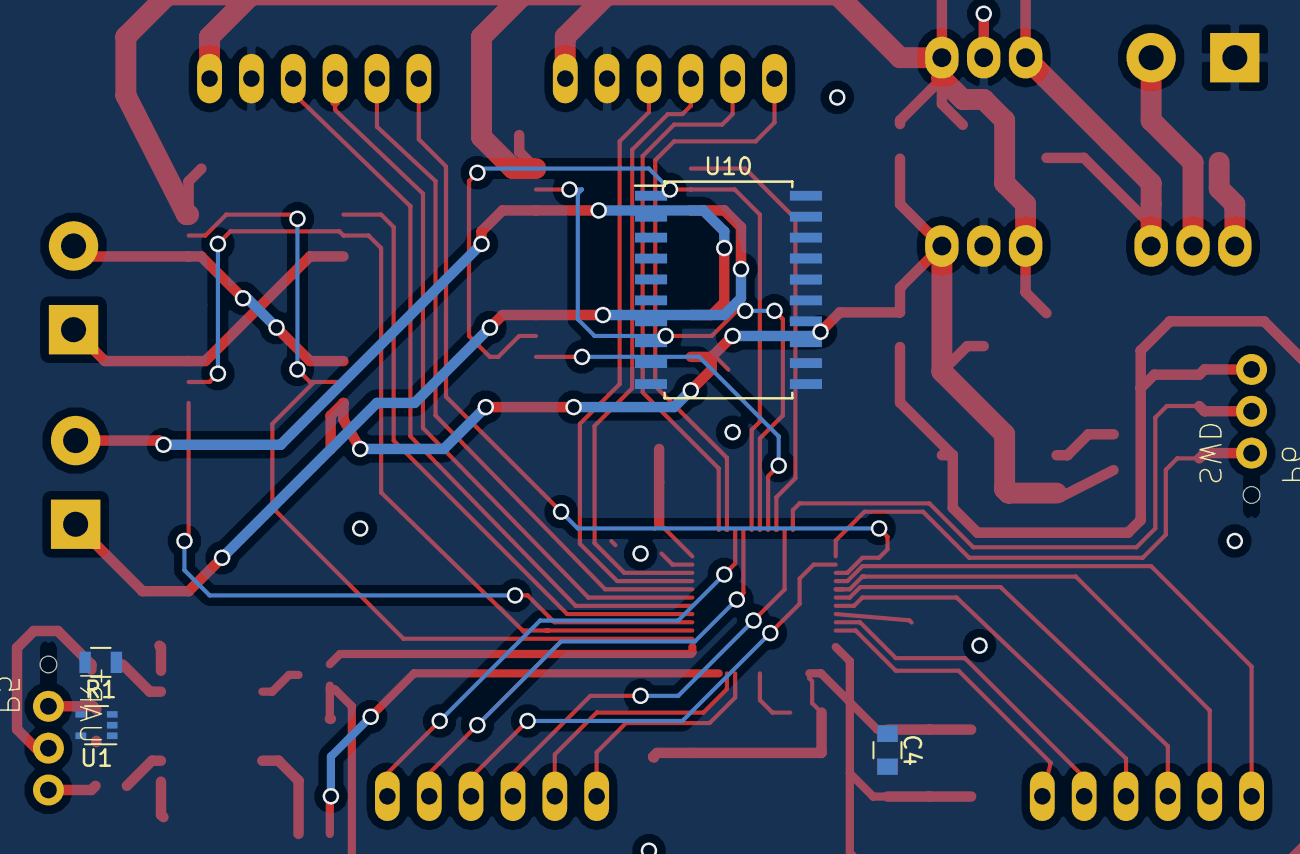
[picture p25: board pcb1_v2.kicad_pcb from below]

Board: 2 copper layers, 53 parts (4 on the bottom side), 52 nets.

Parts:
C1, C6, C8: 0.1u; C_0805
C2, C7: 0.33u; C_0805
C3, C3#2, C3#3, C4, C4#2, C4#3, C11, C12, C13, C14: 100n; C_0805
C5, C5#2, C5#3: 4.7u; C_0805
C9: 10u; C_0805
C10: 100u; C_0805
D1, D2, D3: D; D_0805
P1, P2, P3, P4: CONN_01X06; PINHEAD1-6
P5: UART; SparkFun-1X04
P6: SWD; SparkFun-1X04
P10: M1; bornier2
P11: M2; bornier2
P12: CONN_01X02; bornier2
Q1: IRF9540N; TO-220
R1, R3, R4, R5, R7, R8, R9: 100k; R_0805
R2: 1k; R_0805
R6: 10k; R_0805
S1: SWITCH; SW_SPST_PTS645
U1, U5: 74AHC1G14; SOT-353_SC-70-5
U2, U3: LTV-358T; SW_DIP_x2_W6.15mm_Slide_Omron_A6H
U4: LM7812CT; TO-220
U6: STM32F030C6Tx; LQFP-48_7x7mm_Pitch0.5mm
U7: LM7805CT; TO-220
U8: LM1117-3.3; SOT-223
U9, U10: HL293D; SOIC-20W_7.5x12.8mm_Pitch1.27mm

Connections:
+3V3: C1.2, C3.1, C3#2.1, C3#3.1, C4.1, C4#2.1, C4#3.1, C5.1, C5#2.1, C5#3.1, C10.1, D3.2, P6.4, R3.1, R5.2, R8.2, S1.1, U5.5, U6.1, U6.24, U6.48, U8.2, U8.4
+5C: C8.1, C9.1, C13.1, C14.1, D2.2, D3.1, U7.3, U8.3, U9.20, U10.20
+12C: C6.1, C7.1, C11.1, C12.1, D1.2, D2.1, P1.6, P3.6, U4.3, U7.1, U9.10, U10.10
+24V: P12.2, Q1.2
/Enc0: P4.1, U6.10
/Enc1: P4.2, U6.11
/Enc2: P4.3, U6.33
/Enc3: P4.4, U6.38
/IntRx: R9.1, U6.12
/IntTx: U5.4, U6.13
/SWCLK: P6.2, R4.1, U6.37
/SWDIO: P6.3, R3.2, U6.34
GND: C1.1, C2.2, C3.2, C3#2.2, C3#3.2, C4.2, C4#2.2, C4#3.2, C5.2, C5#2.2, C5#3.2, C6.2, C7.2, C8.2, C9.2, C10.2, C11.2, C12.2, C13.2, C14.2, P1.5, P3.5, P5.1, P6.1, P12.1, R2.2, R4.2, R6.2, S1.2, U1.5, U2.2, U2.3, U3.2, U3.3, U4.2, U5.3, U6.23, U6.47, U7.2, U8.1, U9.4, U9.5, U9.6, U9.7, U9.14, U9.15, U9.16, U9.17, U10.4, U10.5, U10.6, U10.7, U10.14, U10.15, U10.16, U10.17
unnamed: C2.1, D1.1, Q1.3, U4.1
unnamed: P1.1, U6.39
unnamed: P1.2, U6.20
unnamed: P1.3, U6.19
unnamed: P1.4, U6.18
unnamed: P2.1, U6.46
unnamed: P2.2, U6.45
unnamed: P2.3, U6.43
unnamed: P2.4, U6.42
unnamed: P2.5, U6.41
unnamed: P2.6, U6.40
unnamed: P3.1, U6.26
unnamed: P3.2, U6.25
unnamed: P3.3, U6.22
unnamed: P3.4, U6.21
unnamed: P4.5, U6.28
unnamed: P4.6, U6.27
unnamed: P5.2, U1.4
unnamed: P5.3, R1.2
unnamed: P10.1, U9.3, U9.8
unnamed: P10.2, U9.13, U9.18
unnamed: P11.1, U10.3, U10.8
unnamed: P11.2, U10.13, U10.18
unnamed: Q1.1, R2.1
unnamed: R1.1, U3.1
unnamed: R5.1, U6.7
unnamed: R6.1, U6.44
unnamed: R7.1, U1.2, U2.4
unnamed: R8.1, U3.4, U5.2
unnamed: R9.2, U2.1
unnamed: U6.14, U9.2, U9.12
unnamed: U6.15, U9.9, U9.19
unnamed: U6.16, U9.1
unnamed: U6.17, U9.11
unnamed: U6.31, U10.1
unnamed: U6.32, U10.11
unnamed: U6.29, U10.2, U10.12
unnamed: U6.30, U10.9, U10.19
VEE: P5.4, R7.2, U1.3

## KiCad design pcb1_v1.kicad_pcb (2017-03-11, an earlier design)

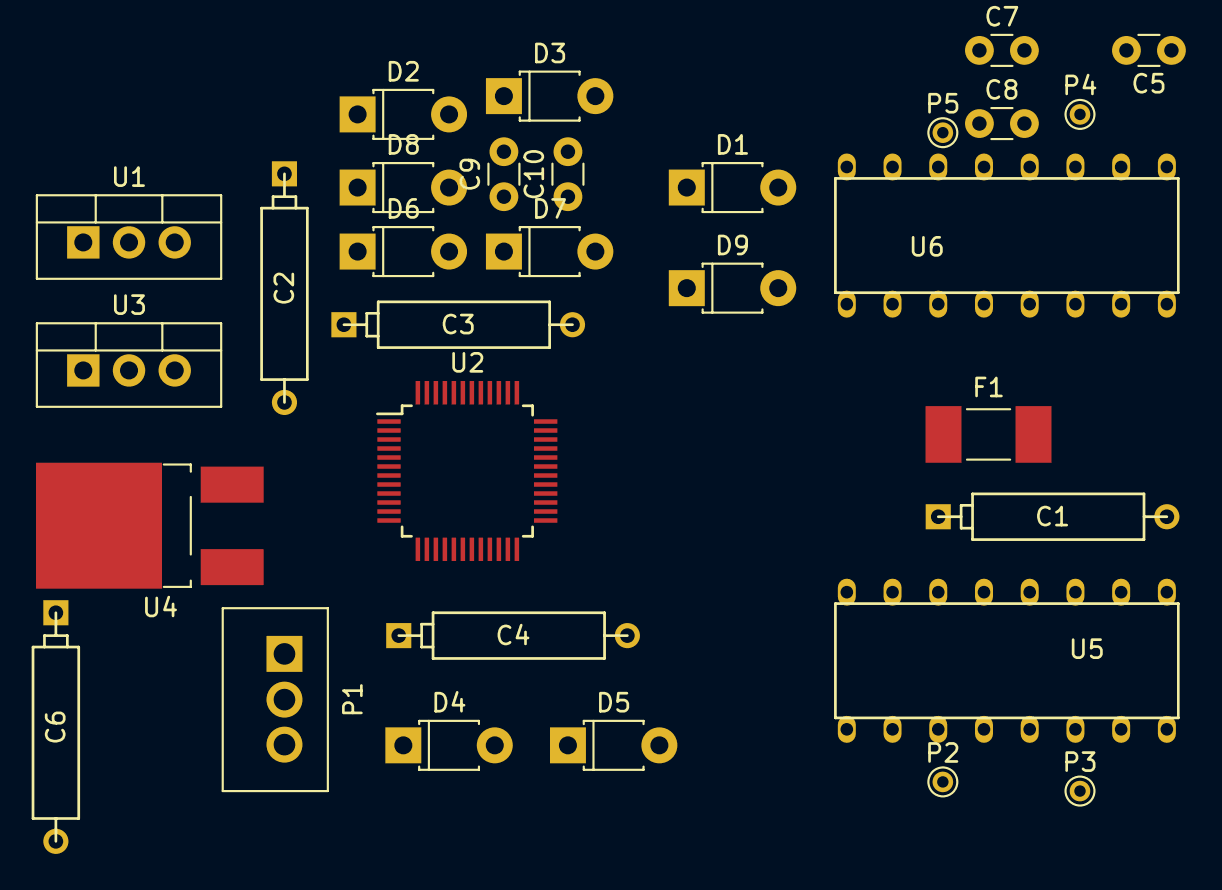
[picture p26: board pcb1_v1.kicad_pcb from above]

Board: 2 copper layers, 31 parts (0 on the bottom side), 17 nets, no tracks yet.

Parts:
C1, C3: 0.33u; CP5
C2, C4: 0.1u; CP5
C5: 0.1u; C_Disc_D3.0mm_W1.6mm_P2.50mm
C6: 2.2u; CP5
C7, C8, C9, C10: 100n; C_Disc_D3.0mm_W1.6mm_P2.50mm
D1: D_Zener; D_T-1_P5.08mm_Horizontal
D2, D3, D4, D5, D6, D7, D8, D9: D; D_T-1_P5.08mm_Horizontal
F1: Fuse; Fuse_CB61F
P1: UART GND, Tx, Rx; Wafer_Vertical10x5.8x7RM2.5-3
P2: M1 A; PINTST
P3: M1 B; PINTST
P4: M2 A; PINTST
P5: M2 B; PINTST
U1: LM7812; TO-220_Vertical
U2: STM32F030C6Tx; LQFP-48_7x7mm_Pitch0.5mm
U3: 7805; TO-220_Vertical
U4: LF33ABDT-TR; TO-252-2Lead
U5, U6: HL293D

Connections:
/3.3V: C6.1, U2.1, U2.9, U2.24, U2.48, U4.3
/5V: C4.1, C5.1, C9.1, C10.1, U4.1, U5.16, U6.16
/12V: C2.1, C3.1, C7.1, C8.1, D2.1, D4.1, D6.1, D8.1, U5.8, U6.8
GND: C1.2, C2.2, C3.2, C4.2, C5.2, C6.2, C7.2, C8.2, C9.2, C10.2, D1.2, D3.2, D5.2, D7.2, D9.2, P1.1, U2.8, U2.23, U2.47, U4.2, U5.4, U5.5, U5.9, U5.12, U5.13, U6.4, U6.5, U6.9, U6.12, U6.13
unnamed: C1.1, D1.1, F1.1
unnamed: D2.2, D3.1, P2.1, U5.3
unnamed: D4.2, D5.1, P3.1, U5.6
unnamed: D6.2, D7.1, P4.1, U6.3
unnamed: D8.2, D9.1, P5.1, U6.6
unnamed: P1.2, U2.12
unnamed: P1.3, U2.13
unnamed: U2.14, U5.2
unnamed: U2.15, U5.7
unnamed: U2.16, U5.1
unnamed: U2.17, U6.1
unnamed: U2.29, U6.2
unnamed: U2.30, U6.7

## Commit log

2017-03-11 almost ready schemat pcb started
    [pcb1.kicad_pcb, pcb1.sch, pcb1_v1.kicad_pcb]
2017-04-02 almoast half ready ;)
    [pcb1.sch, pcb1_v2.kicad_pcb]
